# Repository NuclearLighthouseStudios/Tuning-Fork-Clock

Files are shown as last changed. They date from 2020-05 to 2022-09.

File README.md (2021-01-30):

# Tuning Fork Clock

This repository contains all the files for the Tuning Fork Clock PCB and 3D printed parts.

The PCB was designed for home etching, so the traces are very wide and
the via dimater has been increased so wires can be soldered in to make connections between the layers.

All external connections are broken out on an edge connector at the top that serves as solder pads for making connections.

The "fork mount" directory contains the CAD and STL files for the tuning fork mounting hardware.  
Two 22mH inductors and a 15x5mm neodymium magnet need to be inserted into the base part of the mount.

The polarity of the inductors is not consistent from the factory, so some experimentation is required to get the best results.  
Usually flipping one inductor or the magnet will result in much better vibration of the fork.

The on-board BNC connector can be connected to a scope to observe the output waveform of the pickup.

Check out the [YouTube video](https://www.youtube.com/watch?v=TgB_1jr5b_c) for more info on how it all works.

Also check out [this repository](https://github.com/NuclearLighthouseStudios/Tuning-Fork-Clock-Firmware) for the firmware.

| Reference | Quantity | Value | Description |
| :--- | ---: | ---: | :--- |
| C1 C4 C5 C9 C102 C103 C104 C105 C106 C107 | 10 | 100n | Generic ceramic capacitor |
| C101 | 1 | 100µ | Electrolytic capacitor, 16V |
| C2 C3 | 2 | 47n | Generic ceramic capacitor |
| D1 | 1 | 1N4148 | DO-35 Diode |
| D2 D3 D4 | 3 | | 5mm LED |
| J3 | 1 | | Panel Mount BNC Connector |
| Q1 Q2 Q3 Q4 Q5 Q6 Q7 | 7 | BC547B | 0.1A Ic, 45V Vce, Small Signal NPN Transistor, TO-92 |
| R1 R7 R12 R13 R14 R15 R16 R17 R18 R19 R25 R26 R27 | 13 | 1k | Metal film resistor 1%, DIN 0207, Horizontal |
| R2 R6 | 2 | 1M | Metal film resistor 1%, DIN 0207, Horizontal |
| R20 R21 R22 R23 R24 | 5 | 10k | Metal film resistor 1%, DIN 0207, Vertical |
| R3 | 1 | 4.7k | Metal film resistor 1%, DIN 0207, Horizontal |
| R4 R5 R10 | 3 | 10k | Metal film resistor 1%, DIN 0207, Horizontal |
| R8 R9 | 2 | 100k | Metal film resistor 1%, DIN 0207, Horizontal |
| SW1 | 1 | | Alps EC12E Rotary Encoder with Switch, Vertical |
| U1 | 1 | NE555P | Precision Timers, 555 compatible, PDIP-8 |
| U10 | 1 | 440Hz | Tuning Fork in 3D printed mount |
| U10 | 2 | 22mH | 11mm diameter inductor |
| U10 | 1 | | 15x5mm neodymium rod magnet |
| U2 | 1 | ATtiny4313-PU | 8-Bit Microcontroller, 20Mhz, 4k Flash, 256b RAM |
| U3 | 1 | 74HC595 | 8−Bit shift register |
| U4 U5 U6 U7 U8 | 5 | SC39-11YWA | 7 Segment Display |
| U9 | 1 | L7805 | 5V voltage regulator, TO-220 |

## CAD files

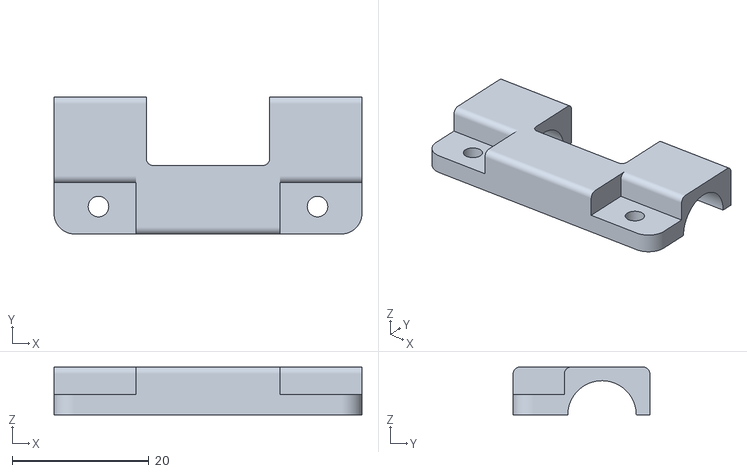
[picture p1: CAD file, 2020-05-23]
fork mount/base-upper.stl
45.0 x 20.0 x 7.00

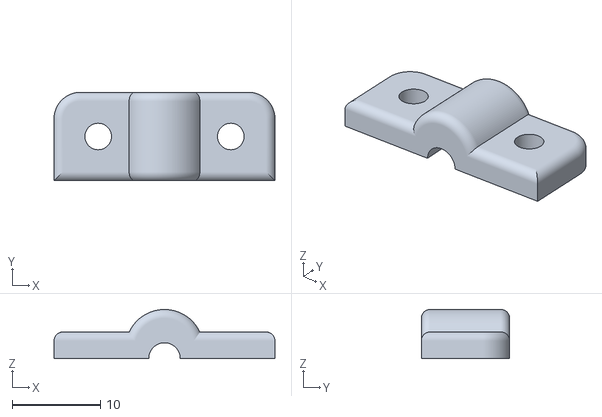
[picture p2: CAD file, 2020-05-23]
fork mount/clamp-upper.stl
25.0 x 10.0 x 5.55

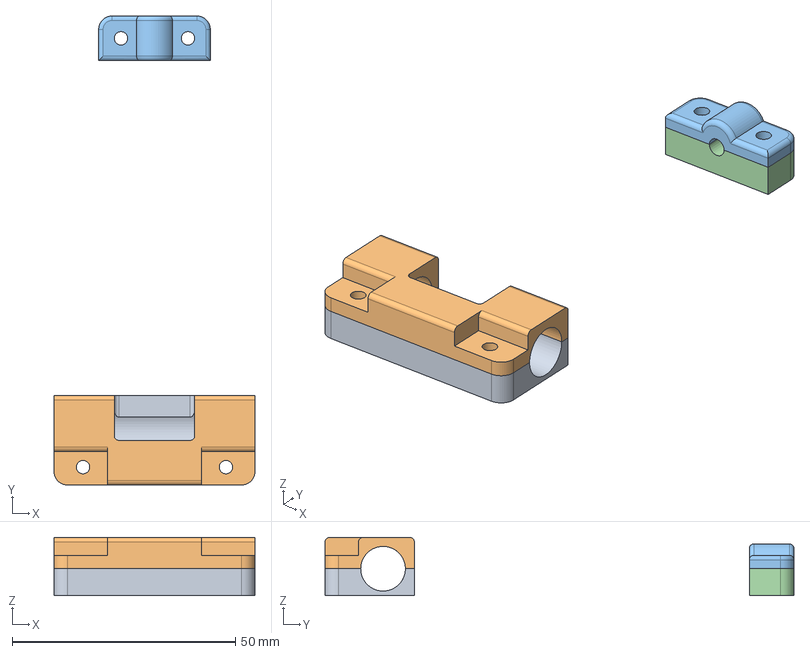
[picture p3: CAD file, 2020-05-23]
fork mount/fork mount.FCStd
45.0 x 105.0 x 13.0 mm
Base Lower
Base Upper
Clamp Upper
Clamp Lower

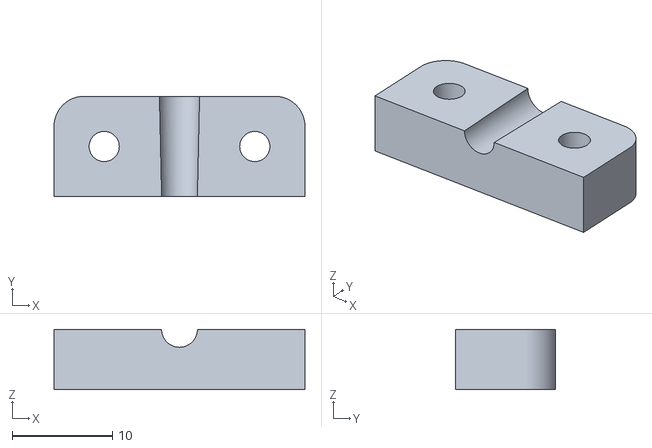
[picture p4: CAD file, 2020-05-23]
fork mount/clamp-lower.stl
25.0 x 10.0 x 6.00

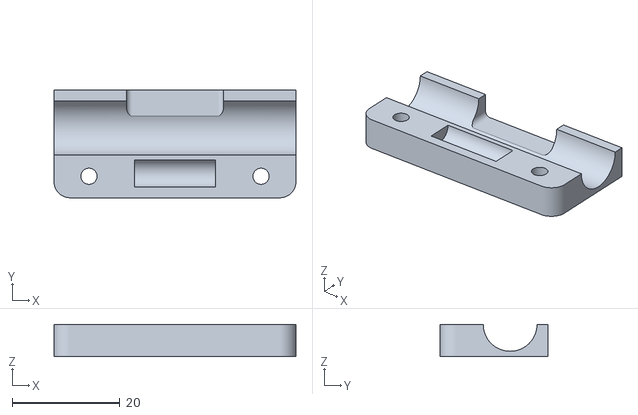
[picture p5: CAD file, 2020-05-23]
fork mount/base-lower.stl
45.0 x 20.0 x 6.00

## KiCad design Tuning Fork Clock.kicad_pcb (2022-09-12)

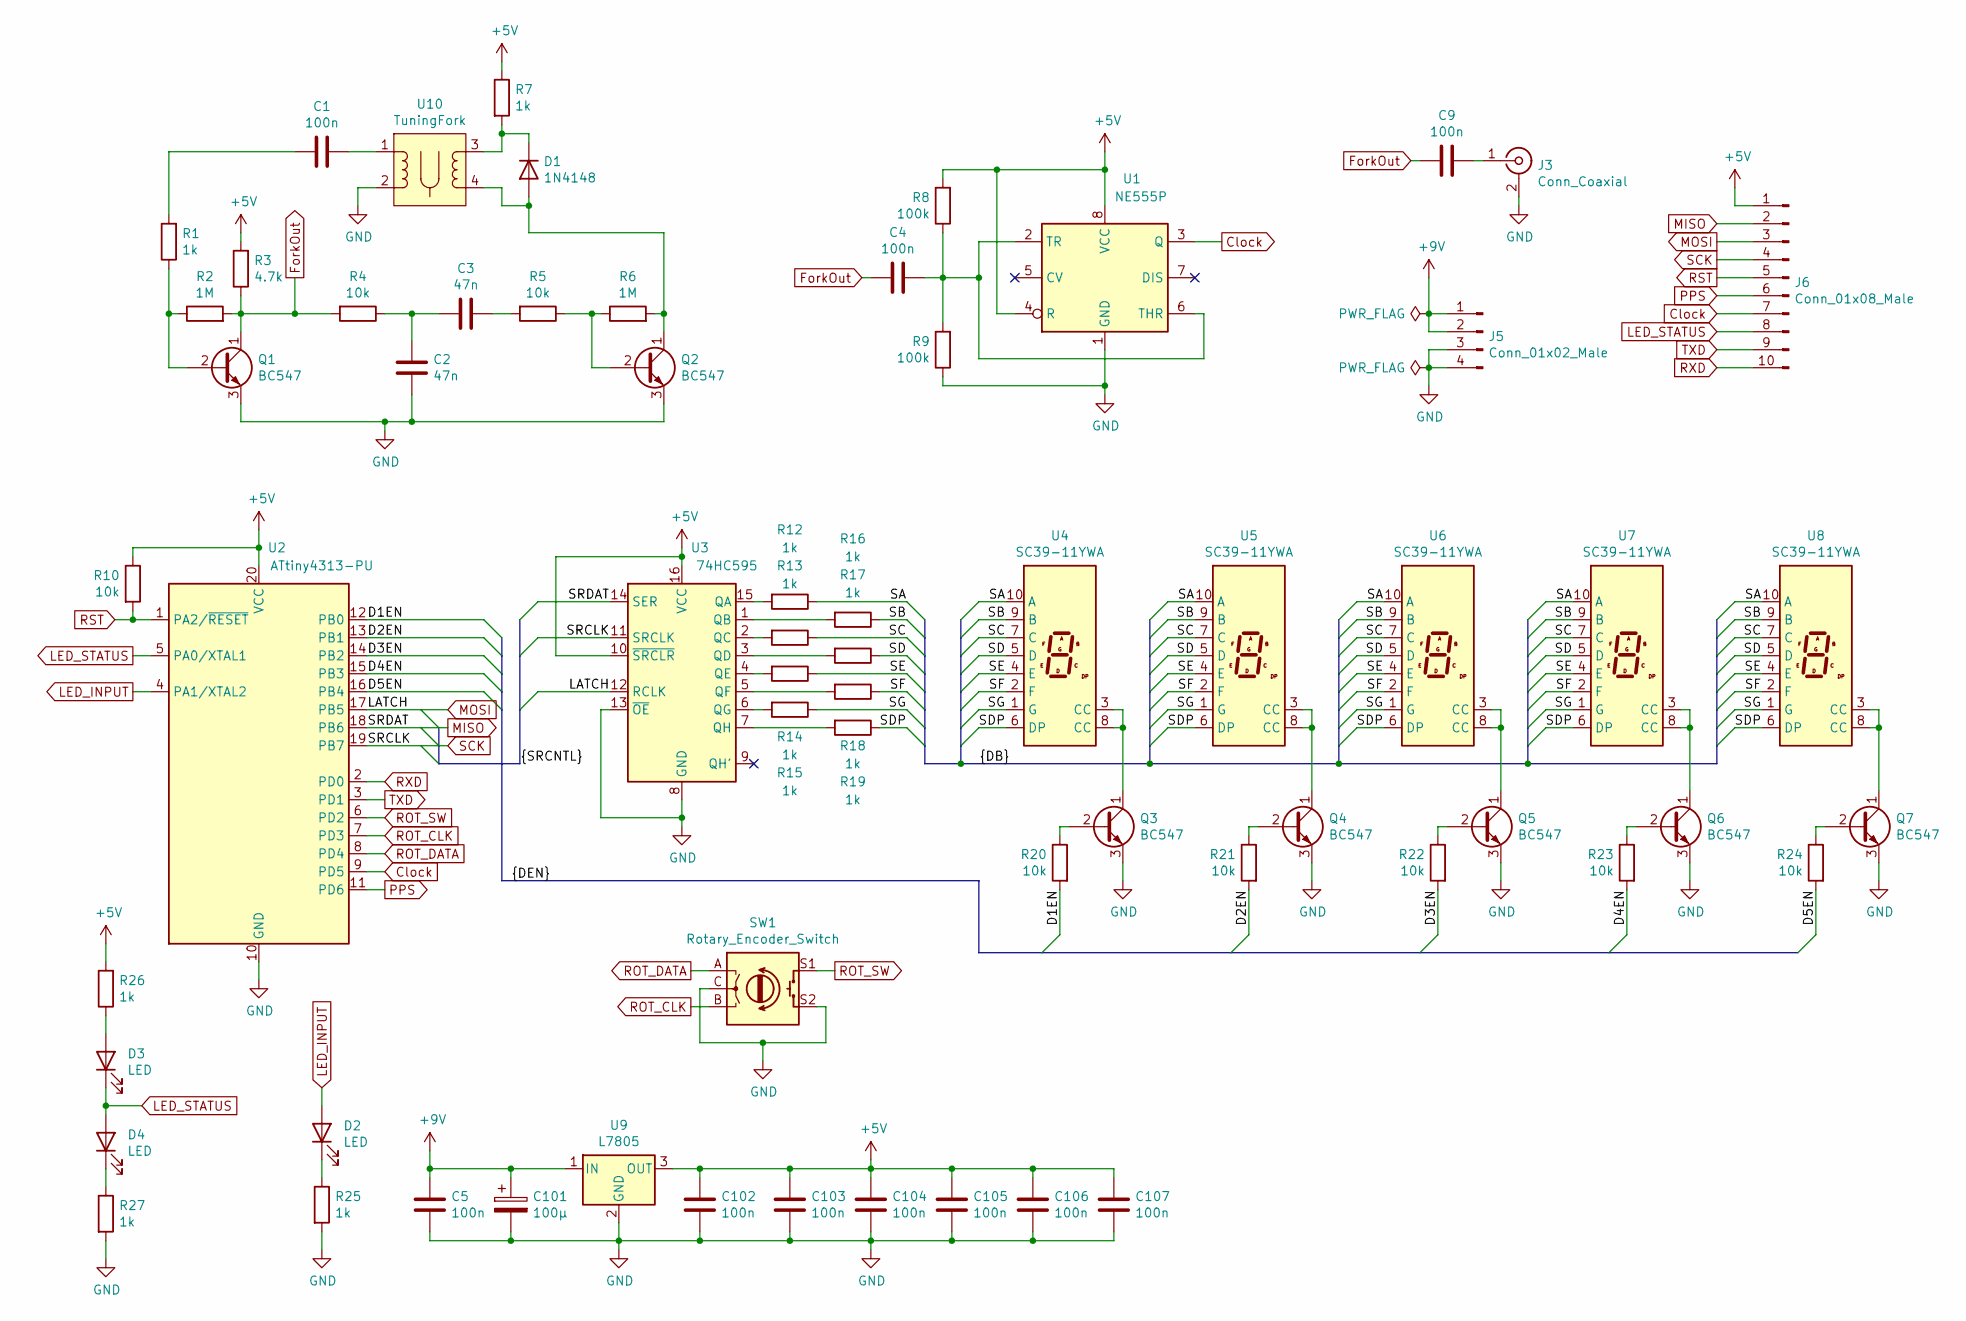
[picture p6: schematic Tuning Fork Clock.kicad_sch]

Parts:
C1, C4, C5, C9, C102, C103, C104, C105, C106, C107: 100n; C_Disc_D4.3mm_W1.9mm_P5.00mm
C2, C3: 47n; C_Disc_D4.3mm_W1.9mm_P5.00mm
C101: 100µ; CP_Radial_D6.3mm_P2.50mm
D1: 1N4148; D_DO-35_SOD27_P7.62mm_Horizontal
D2, D3, D4: LED; LED_D5.0mm_Clear
J3: Conn_Coaxial; BNC_PanelMountable_Vertical
J5: Conn_01x02_Male; EdgeConnPower
J6: Conn_01x08_Male; EdgeConnSignal
Q1, Q2, Q3, Q4, Q5, Q6, Q7: BC547; TO-92_Wide
R1, R7, R12, R13, R14, R15, R16, R17, R18, R19, R25, R26, R27: 1k; R_Axial_DIN0207_L6.3mm_D2.5mm_P10.16mm_Horizontal
R2, R6: 1M; R_Axial_DIN0207_L6.3mm_D2.5mm_P10.16mm_Horizontal
R3: 4.7k; R_Axial_DIN0207_L6.3mm_D2.5mm_P10.16mm_Horizontal
R4, R5, R10: 10k; R_Axial_DIN0207_L6.3mm_D2.5mm_P10.16mm_Horizontal
R8, R9: 100k; R_Axial_DIN0207_L6.3mm_D2.5mm_P10.16mm_Horizontal
R20, R21, R22, R23, R24: 10k; R_Axial_DIN0207_L6.3mm_D2.5mm_P2.54mm_Vertical
SW1: Rotary_Encoder_Switch; RotaryEncoder_Alps_EC12E-Switch_Vertical_H20mm_CircularMoun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
U1: NE555P; DIP-8_W7.62mm_Socket
U2: ATtiny4313-PU; DIP-20_W7.62mm_Socket
U3: 74HC595; DIP-16_W7.62mm_Socket
U4, U5, U6, U7, U8: SC39-11YWA; 7SegmentLED_LTS6760_LTS6780
U9: L7805; TO-220-3_Horizontal_TabDown
U10: TuningFork; Tuning Fork

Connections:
+5V: C102.1, C103.1, C104.1, C105.1, C106.1, C107.1, J6.1, R3.2, R7.1, R8.2, R10.1, R26.2, U1.4 (R), U1.8 (VCC), U2.20 (VCC), U3.10 (~SRCLR), U3.16 (VCC), U9.3 (OUT)
+9V: C5.1, C101.1, J5.1, J5.2, U9.1 (IN)
/D1EN: R20.2, U2.12 (PB0)
/D2EN: R21.2, U2.13 (PB1)
/D3EN: R22.2, U2.14 (PB2)
/D4EN: R23.2, U2.15 (PB3)
/D5EN: R24.2, U2.16 (PB4)
/SA: R12.1, U4.10 (A), U5.10 (A), U6.10 (A), U7.10 (A), U8.10 (A)
/SB: R16.1, U4.9 (B), U5.9 (B), U6.9 (B), U7.9 (B), U8.9 (B)
/SC: R13.1, U4.7 (C), U5.7 (C), U6.7 (C), U7.7 (C), U8.7 (C)
/SD: R17.1, U4.5 (D), U5.5 (D), U6.5 (D), U7.5 (D), U8.5 (D)
/SDP: R19.1, U4.6 (DP), U5.6 (DP), U6.6 (DP), U7.6 (DP), U8.6 (DP)
/SE: R14.1, U4.4 (E), U5.4 (E), U6.4 (E), U7.4 (E), U8.4 (E)
/SF: R18.1, U4.2 (F), U5.2 (F), U6.2 (F), U7.2 (F), U8.2 (F)
/SG: R15.1, U4.1 (G), U5.1 (G), U6.1 (G), U7.1 (G), U8.1 (G)
Clock: J6.7, U1.3 (Q), U2.9 (PD5)
ForkOut: C4.2, C9.2, Q1.1 (C), R2.2, R3.1, R4.2
GND: C2.2, C5.2, C101.2, C102.2, C103.2, C104.2, C105.2, C106.2, C107.2, J3.2 (Ext), J5.3, J5.4, Q1.3 (E), Q2.3 (E), Q3.3 (E), Q4.3 (E), Q5.3 (E), Q6.3 (E), Q7.3 (E), R9.1, R25.2, R27.2, SW1.C, SW1.S2, U1.1 (GND), U2.10 (GND), U3.8 (GND), U3.13 (~OE), U9.2 (GND), U10.2
LED_INPUT: D2.2 (A), U2.4 (PA1/XTAL2)
LED_STATUS: D3.1 (K), D4.2 (A), J6.8, U2.5 (PA0/XTAL1)
MISO: J6.2, U2.18 (PB6), U3.14 (SER)
MOSI: J6.3, U2.17 (PB5), U3.12 (RCLK)
unnamed: C1.1, U10.1
unnamed: C1.2, R1.2
unnamed: C2.1, C3.2, R4.1
unnamed: C3.1, R5.2
unnamed: C4.1, R8.1, R9.2, U1.2 (TR), U1.6 (THR)
unnamed: C9.1, J3.1 (In)
unnamed: D1.1 (K), R7.2, U10.3
unnamed: D1.2 (A), Q2.1 (C), R6.2, U10.4
unnamed: D2.1 (K), R25.1
unnamed: D3.2 (A), R26.1
unnamed: D4.1 (K), R27.1
unnamed: Q1.2 (B), R1.1, R2.1
unnamed: Q2.2 (B), R5.1, R6.1
unnamed: Q3.1 (C), U4.3 (CC), U4.8 (CC)
unnamed: Q3.2 (B), R20.1
unnamed: Q4.1 (C), U5.3 (CC), U5.8 (CC)
unnamed: Q4.2 (B), R21.1
unnamed: Q5.1 (C), U6.3 (CC), U6.8 (CC)
unnamed: Q5.2 (B), R22.1
unnamed: Q6.1 (C), U7.3 (CC), U7.8 (CC)
unnamed: Q6.2 (B), R23.1
unnamed: Q7.1 (C), U8.3 (CC), U8.8 (CC)
unnamed: Q7.2 (B), R24.1
unnamed: R12.2, U3.15 (QA)
unnamed: R13.2, U3.2 (QC)
unnamed: R14.2, U3.4 (QE)
unnamed: R15.2, U3.6 (QG)
unnamed: R16.2, U3.1 (QB)
unnamed: R17.2, U3.3 (QD)
unnamed: R18.2, U3.5 (QF)
unnamed: R19.2, U3.7 (QH)
PPS: J6.6, U2.11 (PD6)
ROT_CLK: SW1.B, U2.7 (PD3)
ROT_DATA: SW1.A, U2.8 (PD4)
ROT_SW: SW1.S1, U2.6 (PD2)
RST: J6.5, R10.2, U2.1 (PA2/~RESET)
RXD: J6.10, U2.2 (PD0)
SCK: J6.4, U2.19 (PB7), U3.11 (SRCLK)
TXD: J6.9, U2.3 (PD1)

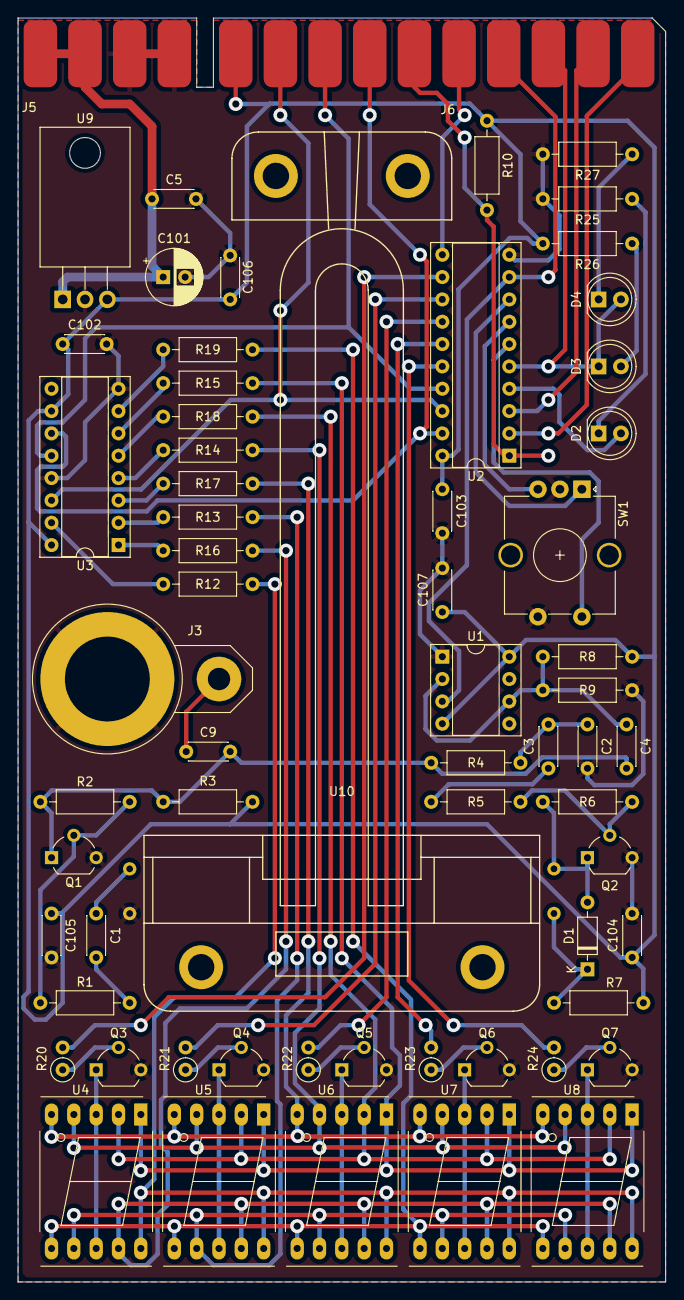
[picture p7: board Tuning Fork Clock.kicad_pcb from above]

Board: 2 copper layers, 73.7 x 143.8 mm, 64 parts (0 on the bottom side), 61 nets.

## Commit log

2020-05-23 Initial Commit! Yay!
    [Tuning Fork Clock.kicad_pcb, Tuning Fork Clock.sch, base-lower.stl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]
2022-09-12 Update to KiCAD 6
    [Tuning Fork Clock.kicad_pcb, Tuning Fork Clock.kicad_sch, Tuning Fork Clock.sch]

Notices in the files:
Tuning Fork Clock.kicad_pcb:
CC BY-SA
